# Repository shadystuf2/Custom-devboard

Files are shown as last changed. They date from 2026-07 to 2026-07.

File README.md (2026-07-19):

# RP2040 Devboard
This is a devboard with an accelerometer/gyroscope and an RP2040 MCU. The design was made using KiCad.  

  

This project is for HORIZONS EUROPA  

Steps taken and the whole work process is logged in JOURNAL.md

**Time taken: 13h**

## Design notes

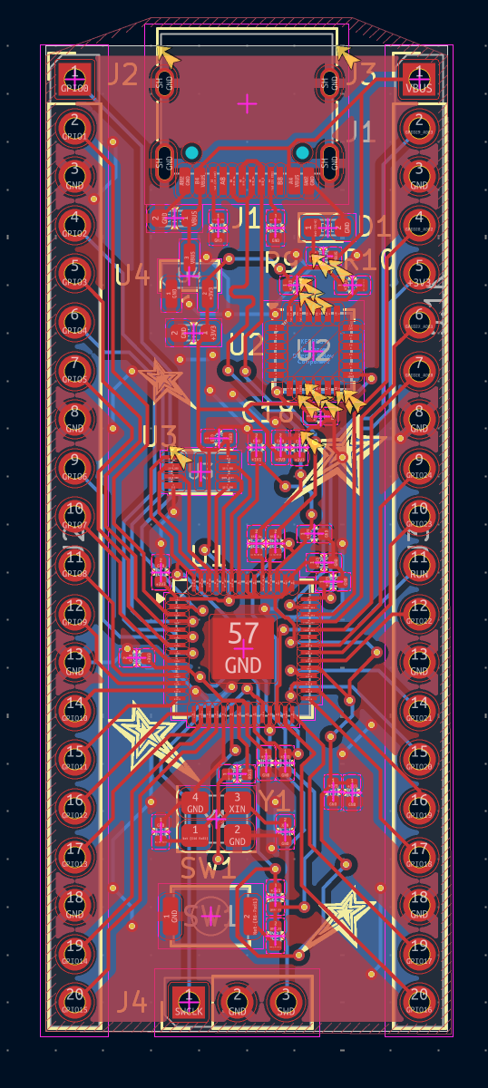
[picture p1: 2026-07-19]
Devboard_design.png

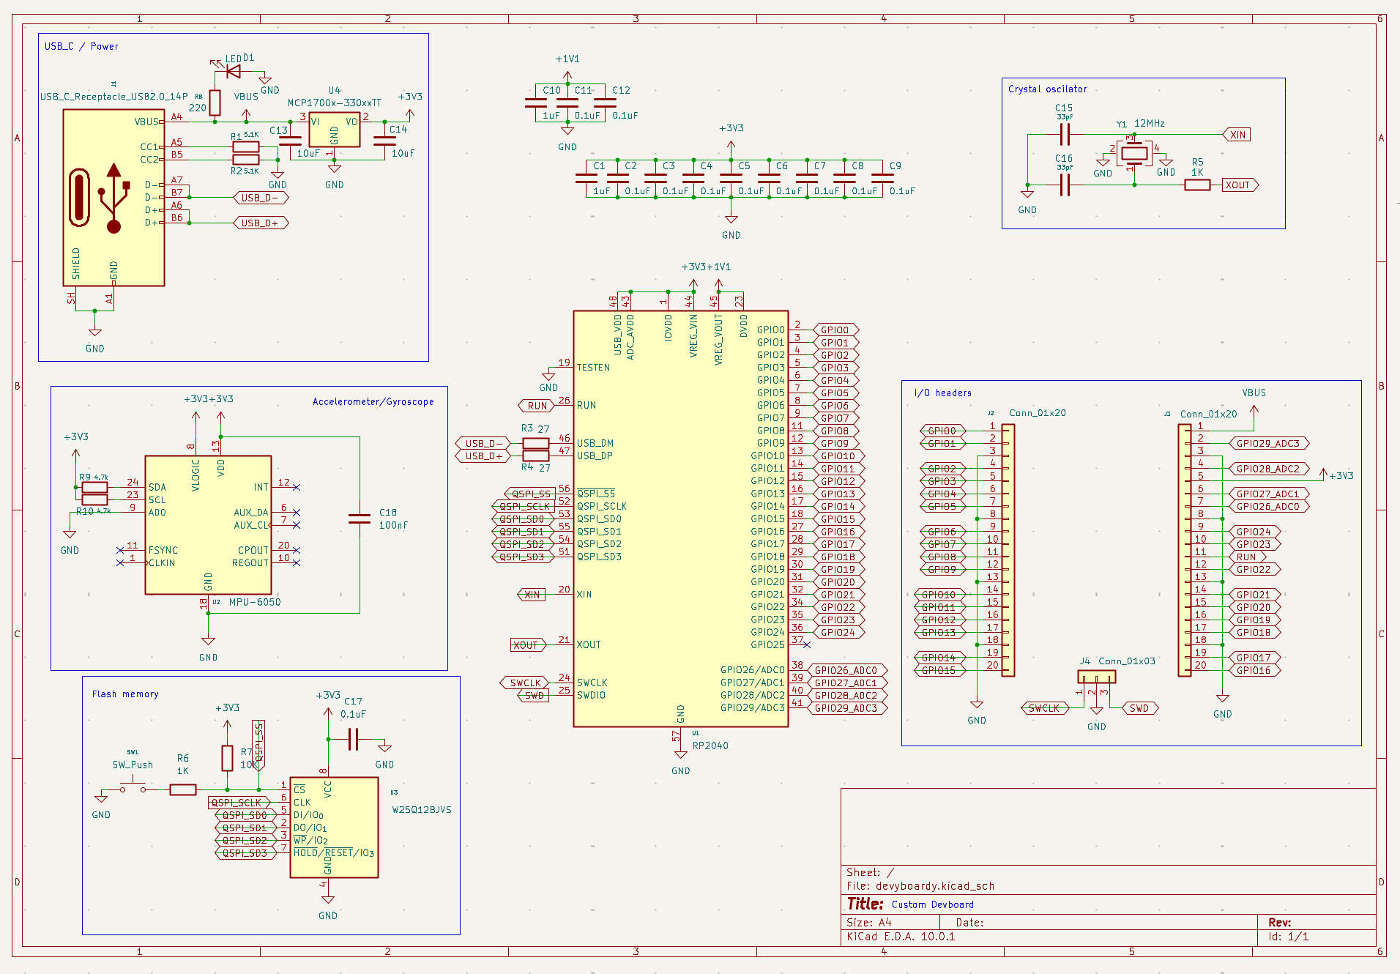
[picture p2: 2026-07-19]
Devborad_schematic.png

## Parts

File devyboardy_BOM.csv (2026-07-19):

Reference | Qty | Value | DNP | Exclude from BOM | Exclude from Board | Footprint | Datasheet
C1,C10 | 2 | 1uF |  |  |  | Capacitor_SMD:C_0402_1005Metric
C2,C3,C4,C5,C6,C7,C8,C9,C11,C12,C17 | 11 | 0.1uF |  |  |  | Capacitor_SMD:C_0402_1005Metric
C13,C14 | 2 | 10uF |  |  |  | Capacitor_SMD:C_0603_1608Metric
C15,C16 | 2 | 33pF |  |  |  | Capacitor_SMD:C_0402_1005Metric
C18 | 1 | 100nF |  |  |  | Capacitor_SMD:C_0402_1005Metric
D1 | 1 | LED |  |  |  | LED_SMD:LED_0603_1608Metric
J1 | 1 | USB_C_Receptacle_USB2.0_14P |  |  |  | Connector_USB:USB_C_Receptacle_HRO_TYPE-C-31-M-12 | https://www.usb.org/sites/default/files/documents/usb_type-c.zip
J2,J3 | 2 | Conn_01x20 |  |  |  | Connector_PinHeader_2.54mm:PinHeader_1x20_P2.54mm_Vertical
J4 | 1 | Conn_01x03 |  |  |  | Connector_PinHeader_2.54mm:PinHeader_1x03_P2.54mm_Vertical
R1,R2 | 2 | 5.1K |  |  |  | Resistor_SMD:R_0402_1005Metric
R3,R4 | 2 | 27 |  |  |  | Resistor_SMD:R_0402_1005Metric
R5,R6 | 2 | 1K |  |  |  | Resistor_SMD:R_0402_1005Metric
R7 | 1 | 10K |  |  |  | Resistor_SMD:R_0402_1005Metric
R8 | 1 | 220 |  |  |  | Resistor_SMD:R_0402_1005Metric
R9,R10 | 2 | 4.7k |  |  |  | Resistor_SMD:R_0402_1005Metric
SW1 | 1 | SW_Push |  |  |  | Button_Switch_SMD:SW_Push_SPST_NO_Alps_SKRK
U1 | 1 | RP2040 |  |  |  | Package_DFN_QFN:QFN-56-1EP_7x7mm_P0.4mm_EP3.2x3.2mm | https://datasheets.raspberrypi.com/rp2040/rp2040-datasheet.pdf
U2 | 1 | MPU-6050 |  |  |  | Sensor_Motion:InvenSense_QFN-24_4x4mm_P0.5mm | https://invensense.tdk.com/wp-content/uploads/2015/02/MPU-6000-Datasheet1.pdf
U3 | 1 | W25Q128JVS |  |  |  | Package_SON:Winbond_USON-8-1EP_3x2mm_P0.5mm_EP0.2x1.6mm | https://www.winbond.com/resource-files/w25q128jv_dtr%20revc%2003272018%20plus.pdf
U4 | 1 | MCP1700x-330xxTT |  |  |  | Package_TO_SOT_SMD:SOT-23 | http://ww1.microchip.com/downloads/en/DeviceDoc/20001826D.pdf
Y1 | 1 | 12MHz |  |  |  | Crystal:Crystal_SMD_3225-4Pin_3.2x2.5mm

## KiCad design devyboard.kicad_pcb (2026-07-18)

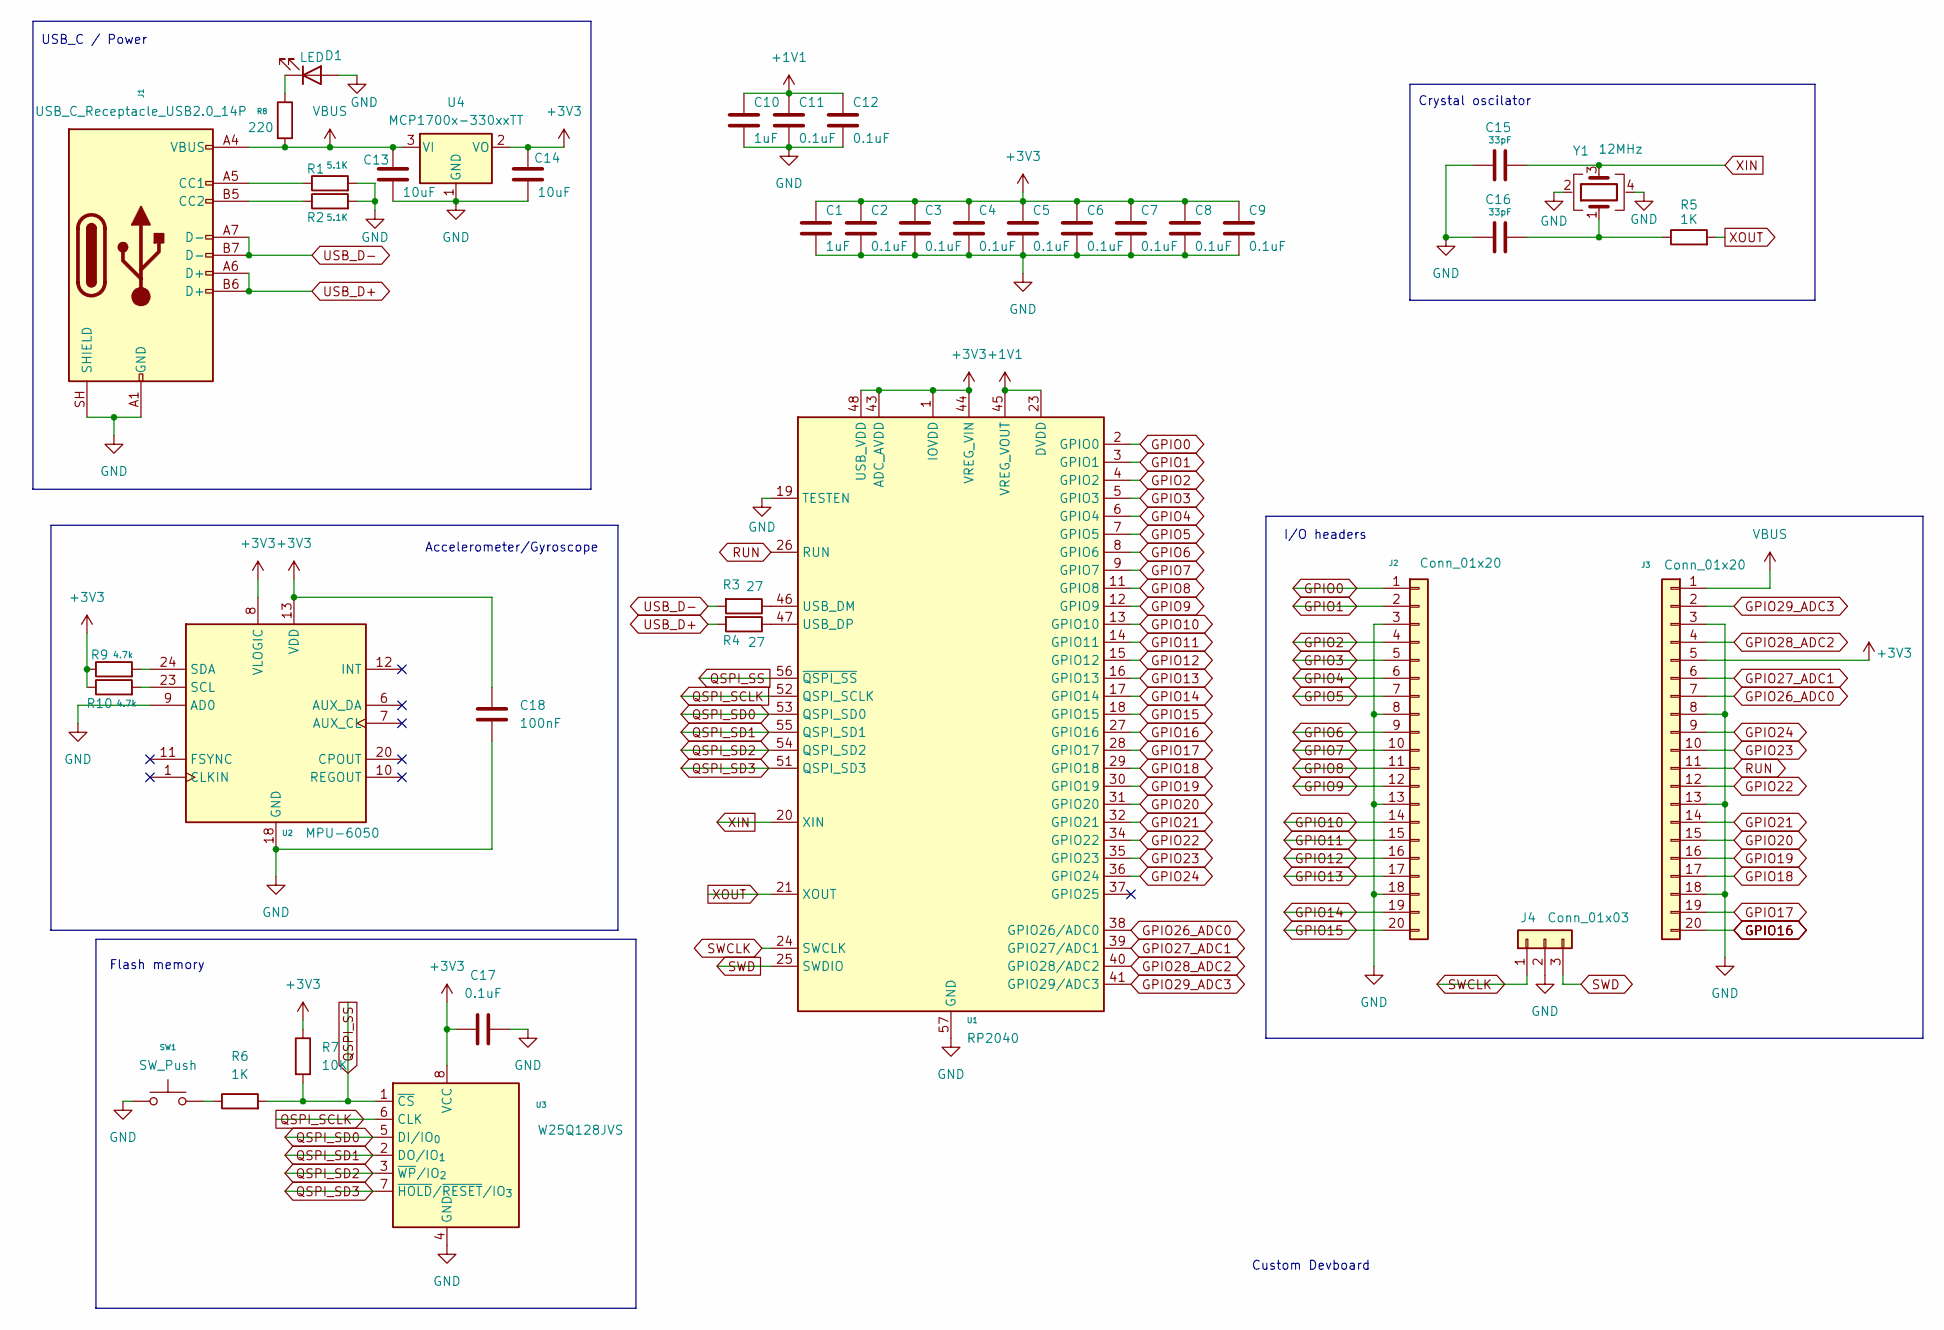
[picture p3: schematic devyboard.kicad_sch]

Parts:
C1, C10: 1uF; C_0402_1005Metric
C2, C3, C4, C5, C6, C7, C8, C9, C11, C12, C17: 0.1uF; C_0402_1005Metric
C13, C14: 10uF; C_0603_1608Metric
C15, C16: 33pF; C_0402_1005Metric
C18: 100nF; C_0402_1005Metric
D1: LED; LED_0603_1608Metric
J1: USB_C_Receptacle_USB2.0_14P; USB_C_Receptacle_HRO_TYPE-C-31-M-12
J2, J3: Conn_01x20; PinHeader_1x20_P2.54mm_Vertical
J4: Conn_01x03; PinHeader_1x03_P2.54mm_Vertical
R1, R2: 5.1K; R_0402_1005Metric
R3, R4: 27; R_0402_1005Metric
R5, R6: 1K; R_0402_1005Metric
R7: 10K; R_0402_1005Metric
R8: 220; R_0402_1005Metric
R9, R10: 4.7k; R_0402_1005Metric
SW1: SW_Push; SW_Push_SPST_NO_Alps_SKRK
U1: RP2040; QFN-56-1EP_7x7mm_P0.4mm_EP3.2x3.2mm
U2: MPU-6050; InvenSense_QFN-24_4x4mm_P0.5mm
U3: W25Q128JVS; Winbond_USON-8-1EP_3x2mm_P0.5mm_EP0.2x1.6mm
U4: MCP1700x-330xxTT; SOT-23
Y1: 12MHz; Crystal_SMD_3225-4Pin_3.2x2.5mm

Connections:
+1V1: C10.1, C11.1, C12.1, U1.23 (DVDD), U1.45 (VREG_VOUT), U1.50 (DVDD)
+3V3: C1.1, C2.1, C3.1, C4.1, C5.1, C6.1, C7.1, C8.1, C9.1, C14.1, C17.2, C18.1, J3.5, R7.1, R9.1, R10.1, U1.1 (IOVDD), U1.10 (IOVDD), U1.22 (IOVDD), U1.33 (IOVDD), U1.42 (IOVDD), U1.43 (ADC_AVDD), U1.44 (VREG_VIN), U1.48 (USB_VDD), U1.49 (IOVDD), U2.8 (VLOGIC), U2.13 (VDD), U3.8 (VCC), U4.2 (VO)
GND: C1.2, C2.2, C3.2, C4.2, C5.2, C6.2, C7.2, C8.2, C9.2, C10.2, C11.2, C12.2, C13.2, C14.2, C15.1, C16.1, C17.1, C18.2, D1.2 (A), J1.A1 (GND), J1.A12 (GND), J1.B1 (GND), J1.B12 (GND), J1.SH (SHIELD), J2.3, J2.8, J2.13, J2.18, J3.3, J3.8, J3.13, J3.18, J4.2, R1.2, R2.2, SW1.1, U1.19 (TESTEN), U1.57 (GND), U2.9 (AD0), U2.18 (GND), U3.4 (GND), U4.1 (GND), Y1.2 (G), Y1.4 (G)
GPIO0: J2.1, U1.2 (GPIO0)
GPIO1: J2.2, U1.3 (GPIO1)
GPIO2: J2.4, U1.4 (GPIO2)
GPIO3: J2.5, U1.5 (GPIO3)
GPIO4: J2.6, U1.6 (GPIO4)
GPIO5: J2.7, U1.7 (GPIO5)
GPIO6: J2.9, U1.8 (GPIO6)
GPIO7: J2.10, U1.9 (GPIO7)
GPIO8: J2.11, U1.11 (GPIO8)
GPIO9: J2.12, U1.12 (GPIO9)
GPIO10: J2.14, U1.13 (GPIO10)
GPIO11: J2.15, U1.14 (GPIO11)
GPIO12: J2.16, U1.15 (GPIO12)
GPIO13: J2.17, U1.16 (GPIO13)
GPIO14: J2.19, U1.17 (GPIO14)
GPIO15: J2.20, U1.18 (GPIO15)
GPIO16: J3.20, U1.27 (GPIO16)
GPIO17: J3.19, U1.28 (GPIO17)
GPIO18: J3.17, U1.29 (GPIO18)
GPIO19: J3.16, U1.30 (GPIO19)
GPIO20: J3.15, U1.31 (GPIO20)
GPIO21: J3.14, U1.32 (GPIO21)
GPIO22: J3.12, U1.34 (GPIO22)
GPIO23: J3.10, U1.35 (GPIO23)
GPIO24: J3.9, U1.36 (GPIO24)
GPIO26_ADC0: J3.7, U1.38 (GPIO26/ADC0)
GPIO27_ADC1: J3.6, U1.39 (GPIO27/ADC1)
GPIO28_ADC2: J3.4, U1.40 (GPIO28/ADC2)
GPIO29_ADC3: J3.2, U1.41 (GPIO29/ADC3)
unnamed: C16.2, R5.1, Y1.1
unnamed: D1.1 (K), R8.1
unnamed: J1.A5 (CC1), R1.1
unnamed: J1.B5 (CC2), R2.1
unnamed: R6.1, SW1.2
unnamed: R3.1, U1.46 (USB_DM)
unnamed: R4.1, U1.47 (USB_DP)
unnamed: R10.2, U2.23 (SCL)
unnamed: R9.2, U2.24 (SDA)
QSPI_SCLK: U1.52 (QSPI_SCLK), U3.6 (CLK)
QSPI_SD0: U1.53 (QSPI_SD0), U3.5 (DI/IO_{0})
QSPI_SD1: U1.55 (QSPI_SD1), U3.2 (DO/IO_{1})
QSPI_SD2: U1.54 (QSPI_SD2), U3.3 (~WP/IO_{2})
QSPI_SD3: U1.51 (QSPI_SD3), U3.7 (~HOLD/~RESET/IO_{3})
QSPI_SS: R6.2, R7.2, U1.56 (~QSPI_SS), U3.1 (~CS)
RUN: J3.11, U1.26 (RUN)
SWCLK: J4.1, U1.24 (SWCLK)
SWD: J4.3, U1.25 (SWDIO)
USB_D+: J1.A6 (D+), J1.B6 (D+), R4.2
USB_D-: J1.A7 (D-), J1.B7 (D-), R3.2
VBUS: C13.1, J1.A4 (VBUS), J1.A9 (VBUS), J1.B4 (VBUS), J1.B9 (VBUS), J3.1, R8.2, U4.3 (VI)
XIN: C15.2, U1.20 (XIN), Y1.3
XOUT: R5.2, U1.21 (XOUT)

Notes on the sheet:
I/O headers
Flash memory
USB_C / Power
Accelerometer/Gyroscope
Crystal oscilator
Custom Devboard

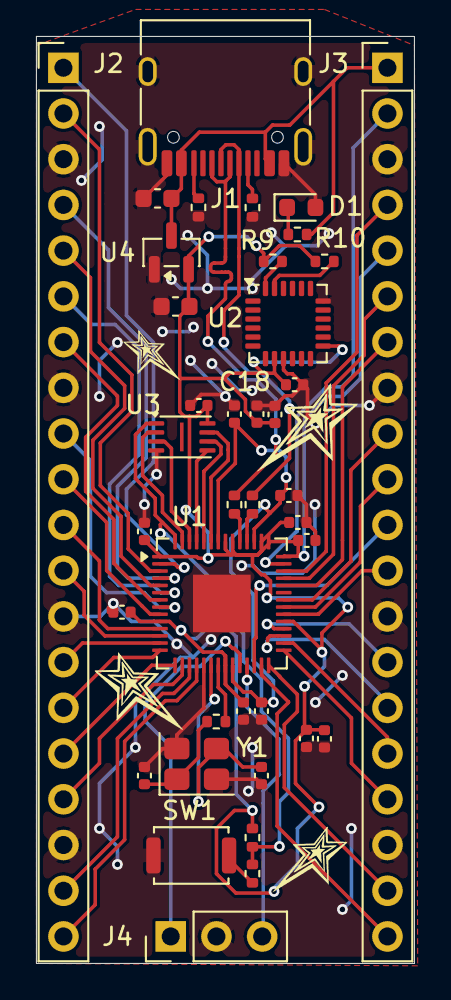
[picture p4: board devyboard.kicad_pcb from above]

Board: 2 copper layers, 21.0 x 51.5 mm, 39 parts (0 on the bottom side), 55 nets.

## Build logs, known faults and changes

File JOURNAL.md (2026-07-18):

---
Title: "Fancy Devboard"
Author: "Nomeda"
Description: "A custom PCB that has an RP2040 and an accelerometer"
Created at: "2026-06-11"
---

THIS PROJECT IS FOR HORIZONS EUROPA

## June 11th: Got schematics done and started the layout
I got the inspiration for this from one of the starter projects in STASIS but decided to add some sensors and designs. I followed the tutorial for schematics on KiCad. Honestly, I struggled with I/O labels a bit, since the
shapes sometimes don't make sense. Also, dealing with the crystal oscillator was funny, since we thought that we had the wrong schematic,
since it had only 3 pins. Turns out the 4th one was hidding under one of the other pins and we had to modify the schema manually. 
Then we were looking for footprints which was a very tedious job. I also helped out my friend, as he was struggling with the overall 
logic of the schematic.  

Finished schematic:


**Total time spent: 4h**

## June 18th: Finished layout and routing
This is where I stopped following the tutorial. The layout and routing is completely my own. I arranged the componenets on a basic rectangle, since I want the devboard to be compact and usable. Then (very convinient timing) I decided,
that I want to add a sensor and chose an accelerometer and gyroscope MPU-6050. I noticed that a switch that was in the schematic was 
missing, so I had to reload and delete and add it several times. Then I started routing and had to rearrange the components so that 
everything would fit. Many hours later, I added ground fill, saw the number of errors that popped up and closed my PC immedietly.  

Layout:  
  

Routed version:  


**Total time spent: 4h**

## July 7th: Ground fill and Debugging
Finally, the much dreader debugging session. Apparently, my wiring was a bit too random with too many vias so making space for ground fill 
was quite time consuming. After that I just went through the errors in the design rules checker one by one and cleared them. It finally looked
polished and I was very happy with how it turend out. The only thing that I wanted to add was a design.  
Also, later I realized that I can do ground fill on both layers, but I somehowd managed and did my whole routing with only the front filled. 
And I cleared all errors. No wonder it took so long. But lesson learnt.  

Devboard with ground fill: 


**Total time spent: 3h**

## July 15th: Design  

I removed all the component labels. Initially, I wanted to do a constelation of stars, then star people, but it was not very
visible so I ended up adding just these giant stars. I did not really know what would be a convenient software that could 
export .SVG files so I used Boxy SVG for my designs and drew them.  

Star people design (not mine, credits to artist but I don't know who they are beacuse the person who posted this on pinterest doesn't say):  

  

Final product:  



**Total time spent: 2h**

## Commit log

2026-07-18 Added schematic of devboard
    [devyboard.kicad_sch]
2026-07-18 added pcb file of devboard
    [devyboard.kicad_pcb]
2026-07-18 added gerber files
    [devyboardy-B_Cu.gbr, devyboardy-B_Mask.gbr, devyboardy-B_Paste.gbr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]
2026-07-18 moved gerbers
    [devyboardy-B_Cu.gbr, devyboardy-B_Mask.gbr, devyboardy-B_Paste.gbr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]
2026-07-18 added gerber back to their file
    [devyboardy-B_Cu.gbr, devyboardy-B_Mask.gbr, devyboardy-B_Paste.gbr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]
2026-07-19 added BOM
    [devyboardy_BOM.csv]
